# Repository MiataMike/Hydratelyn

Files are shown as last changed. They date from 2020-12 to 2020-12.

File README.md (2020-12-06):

# Hydratelyn
This project is a soil moisture sensor that can be interfaced to a MyDAQ, or just about any DAQ with a voltage input

## Probe selection
Most soil probes are made from PCB material, with ENIG plating (at best), which corrodes over time due to electrolysis
Hydratelyn uses 2mm pencil leads as the probes, which won't rust. The resistance of the probes was measured around 15 Ohms
from end to end, which is insignificant relative to the resistance of the soil

## Soil resistance
To figure out what resistance range we're trying to measure, I placed 2 leads in my plants' soil while it was dry and checked with a multimeter. It read 30M, which is very high. After watering it dropped to 7k.

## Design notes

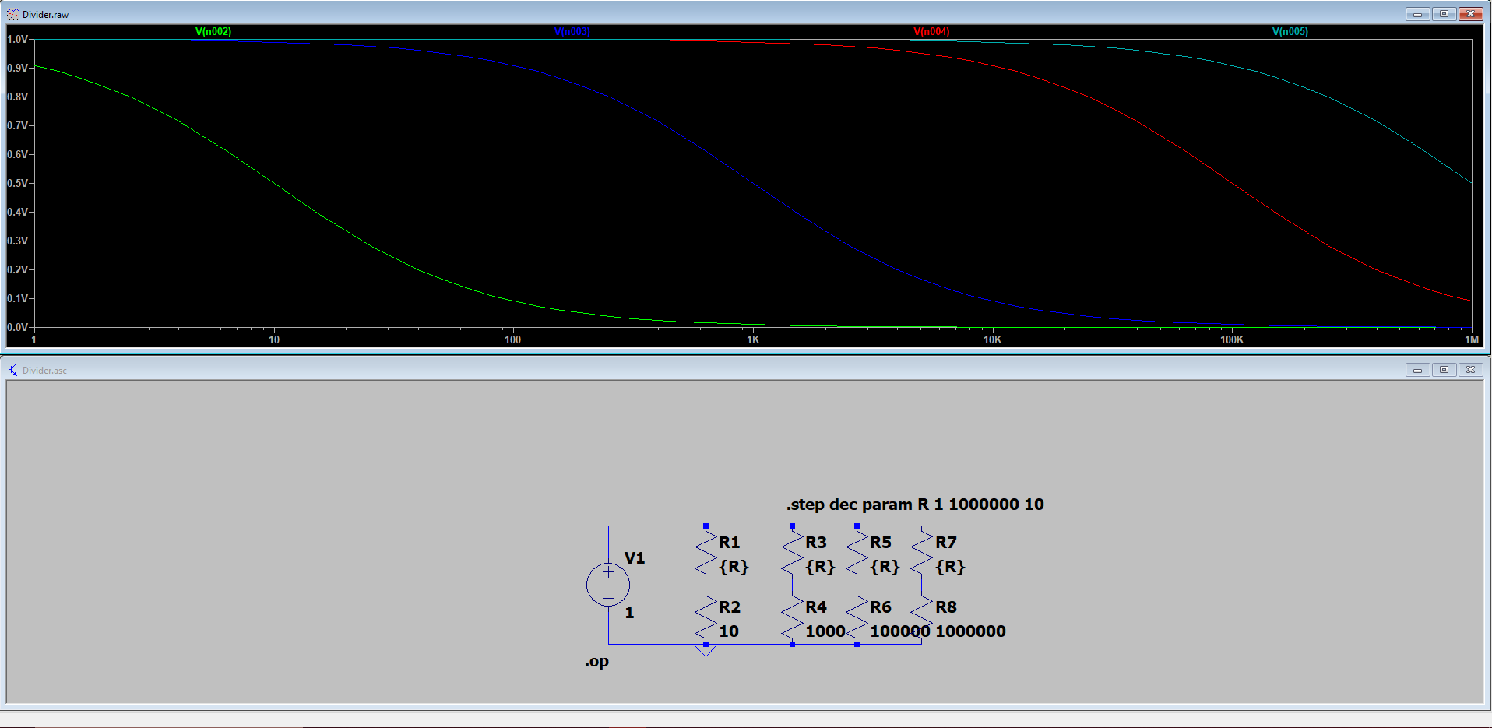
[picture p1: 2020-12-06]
Plots.png

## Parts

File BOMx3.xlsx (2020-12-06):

Index | Quantity | Part Number | Manufacturer Part Number | Description | Customer Reference | Available | Backorder | Unit Price | Extended Price USD
1 | 3 | CT6EP205-ND | CT6EP205 | TRIMMER 2M OHM 0.5W PC PIN TOP |  | 3 | 0 | 0.78 | 2.34
2 | 10 | 36-9900-ND | 9900 | MACHINE SCREW PAN PHILLIPS 4-40 |  | 10 | 0 | 0.1 | 1.00
3 | 10 | 36-4694-ND | 4694 | HEX NUT 3/16" STEEL 4-40 |  | 10 | 0 | 0.1 | 1.00
4 | 3 | 296-TLV9102IDRCT-ND | TLV9102IDR | IC OPAMP POWER 2 CIRCUIT 8SOIC |  | 3 | 0 | 1 | 3.00
5 | 6 | 478-8741-1-ND | 709155001610004 | CONN SPRING BATTERY 1POS SMD |  | 6 | 0 | 0.26 | 1.56
6 | 3 | 277-1860-ND | 1984633 | TERM BLK 4POS SIDE ENT 3.5MM PCB |  | 3 | 0 | 0.95 | 2.85
7 | 5 | 1276-1075-1-ND | CL31A106KAHNNNE | CAP CER 10UF 25V X5R 1206 |  | 5 | 0 | 0.2 | 1.00
8 | 10 | RMCF1206FT100KCT-ND | RMCF1206FT100K | RES 100K OHM 1% 1/4W 1206 |  | 10 | 0 | 0.031 | 0.31

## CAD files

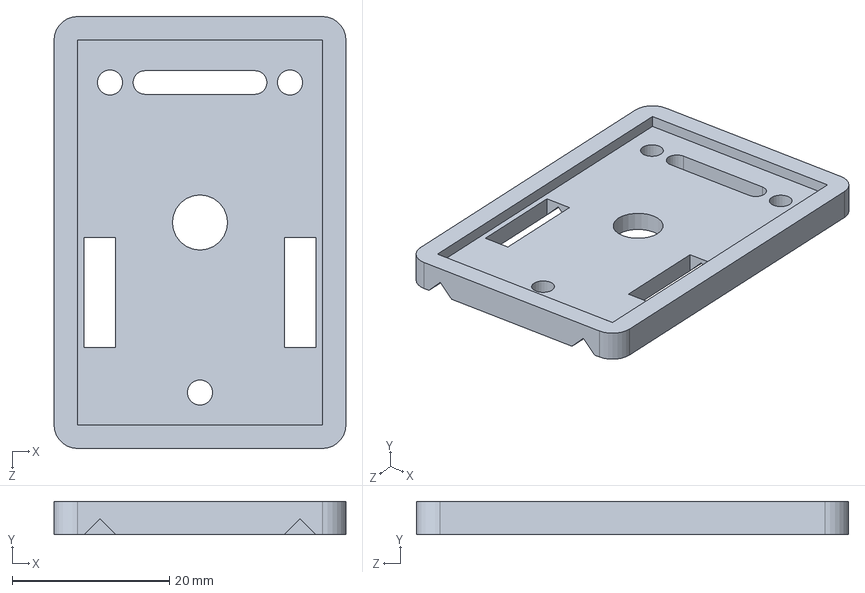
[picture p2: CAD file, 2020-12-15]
3D files/SensorTop.SLDPRT
37.1 x 4.20 x 54.9 mm

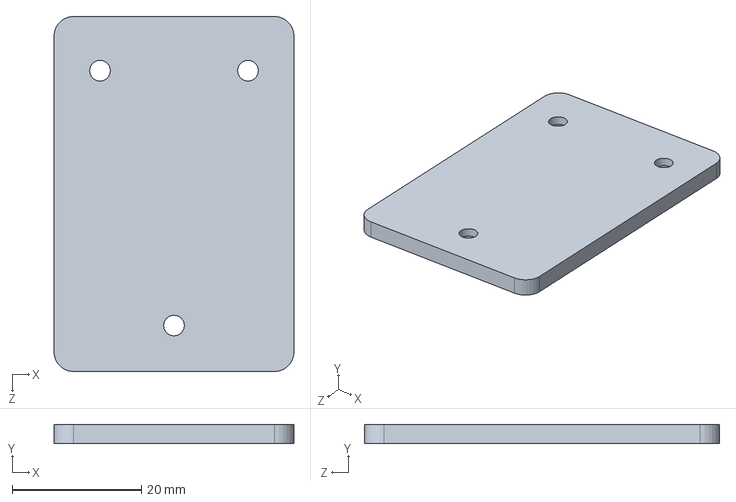
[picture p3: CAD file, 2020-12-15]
3D files/SensorBottom.SLDPRT
37.1 x 3.00 x 54.9 mm

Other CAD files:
3D files/SensorBottom.3mf
3D files/SensorBottom.STL
3D files/SensorTop.3mf
3D files/SensorTop.STL

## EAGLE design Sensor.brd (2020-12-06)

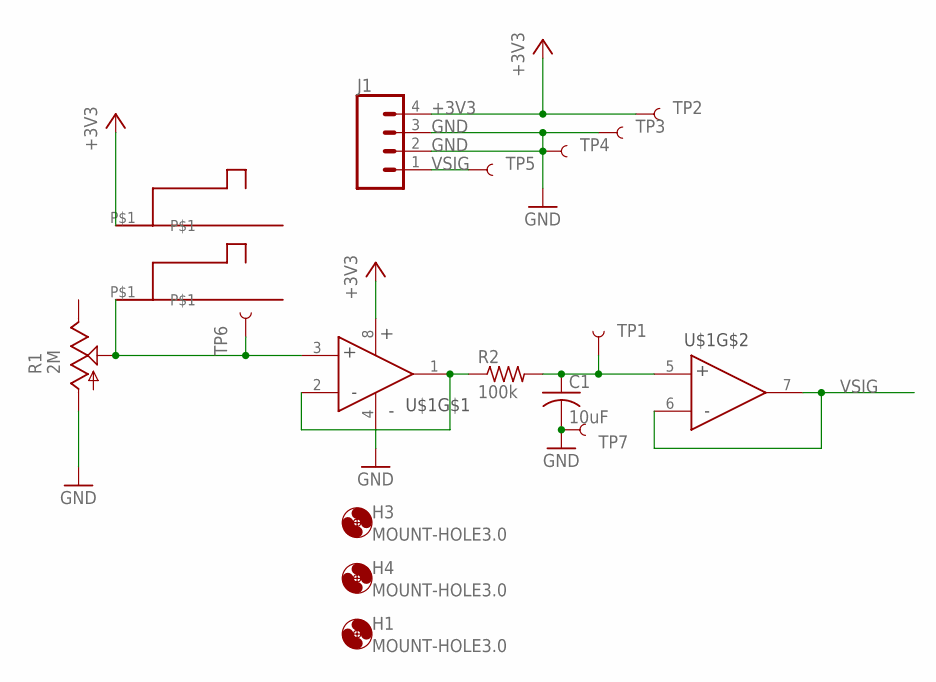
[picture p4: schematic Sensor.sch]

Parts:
C1: 10uF; C1206
H1, H3, H4: MOUNT-HOLE3.0; 3,0
J1: CONN_04SCREW; SCREWTERMINAL-3.5MM-4
R1: 2M; CT6
R2: 100k; R1206
TP1, TP2, TP3, TP4, TP5, TP6, TP7: TEST-POINT3X5; PAD.03X.05
U$1: TLV9102; SOIC-8
U$2, U$3: 709155001610004

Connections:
+3V3: J1.4, TP2.P$1, U$1.8 (V+), U$2.P$1
GND: C1.2, J1.2, J1.3, R1.A, TP3.P$1, TP4.P$1, TP7.P$1, U$1.4 (V-)
unnamed: C1.1, R2.2, TP1.P$1, U$1.5 (+)
unnamed: R1.S, TP6.P$1, U$1.3 (NONINVERTING), U$3.P$1
unnamed: R2.1, U$1.1 (OUT), U$1.2 (INVERTING)
VSIG: J1.1, TP5.P$1, U$1.6 (-), U$1.7 (OUT)

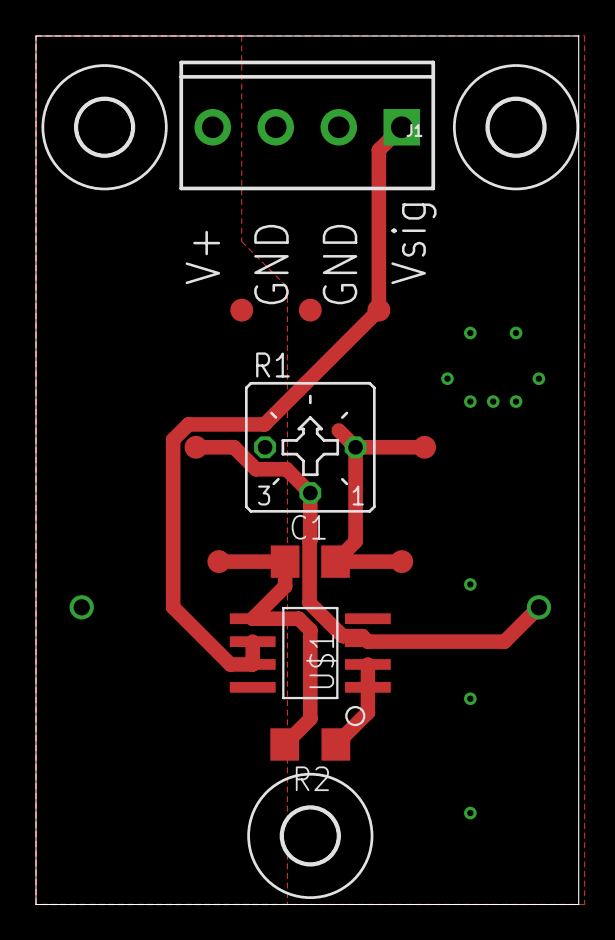
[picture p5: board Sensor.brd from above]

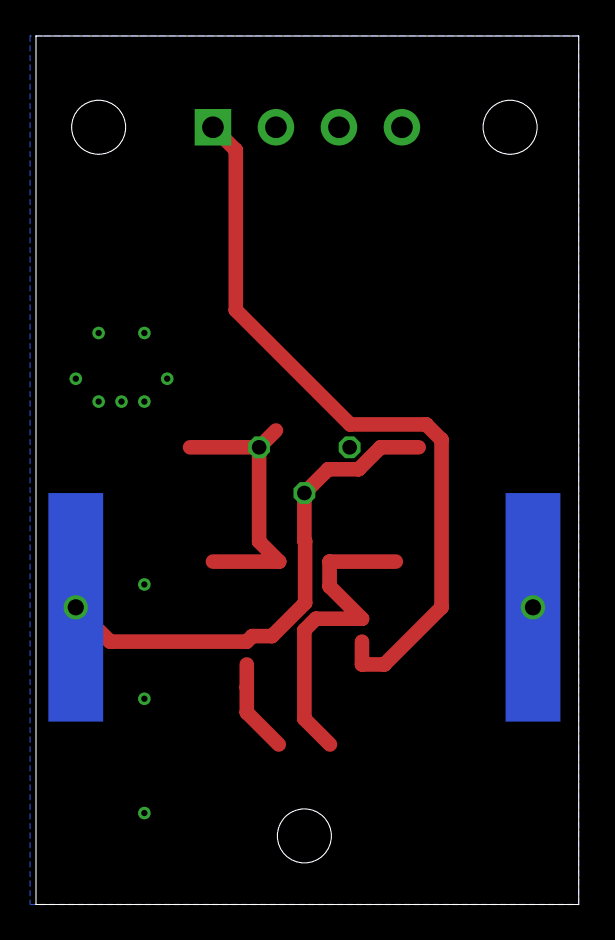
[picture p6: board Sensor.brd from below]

Board: 2 copper layers, 30.1 x 48.2 mm, 17 parts (2 on the bottom side), 6 nets.

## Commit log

2020-12-05 Made board, passes DRC, gerbers generated
    [Sensor.brd, Sensor.sch]
2020-12-06 Changed board dimensions
    [Sensor.brd, Sensor.sch]
2020-12-06 Added cart from digikey, updated schematic with values
    [BOMx3.xlsx, Sensor.brd, Sensor.sch]
2020-12-15 added files for board holder, renamed zip
    [SensorBottom.3mf, SensorBottom.SLDPRT, SensorBottom.STL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]

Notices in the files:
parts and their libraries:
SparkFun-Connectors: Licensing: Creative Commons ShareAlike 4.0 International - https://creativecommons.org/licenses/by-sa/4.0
